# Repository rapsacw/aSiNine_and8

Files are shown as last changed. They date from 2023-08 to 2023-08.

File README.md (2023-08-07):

# aSiNine_and8
Small (46.5x73.2mm) BM1397 based standalone bitcoin miner

Revision 04k, remarks:
- PWM fan: do not populate T2,JP1 & R10, unless you want to use that feature (no software support yet), replace T2 with a mosfet if you want to use it, a transistor will pull gpio9 low at startup locking the esp in programming mode.
- programming first time: some esp's will not enter programming mode automatically, in that case short gpio9 to ground at power-up (gpio9 is connected to the encircled via close to the esp32-c3). Updating the firmware is best done through OTA @ <your miner's ip address>/update). You can also flash the esp with the ElegantOTA demo and then flash it first time over the air.
- Powering the miner: use a 5V/3A usb charger for low power application (upto ~250GHs). If you want more powerrr use the screw terminal to connect a 9-12V power supply. I use a usb trigger (like https://www.aliexpress.com/item/1005004562492420.html) set to 9V connected to a usb charger with PD (use a high efficiency charger like https://www.aliexpress.com/item/1005004530223949.html). IMPORTANT: only connect the miner with ONE of the power inputs. Powering the miner with more than 5V and connecting it to a PC will damage the miner and the pc!!!!
- Cooling: I use a 7cm piece of https://www.aliexpress.com/item/1005001772072504.html with a 5cm 5V fan (runs on 3.3V when connected to X1) like https://www.aliexpress.com/item/1005003059434065.html strapped to the heatsink and board with tie wraps. Don't forget to use some (non-conductive!) thermal compound. This fan/heatsink combo will allow the miner to be run at upto 320GHs while staying (just) below my max asic temperature of 60C and is virtually silent.
- The firmware used is bm1397.ino.bin included in this repo, and can be used until I update & publish the source code of my firmware.

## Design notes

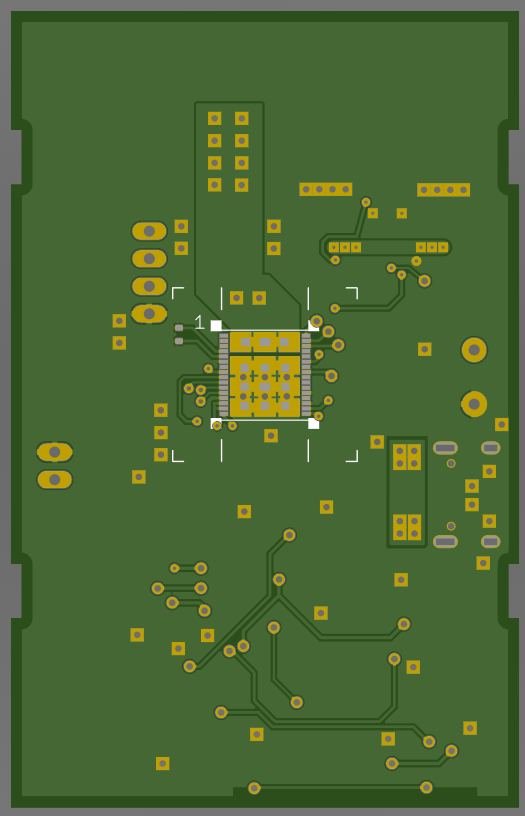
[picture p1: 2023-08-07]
and8bottom.png

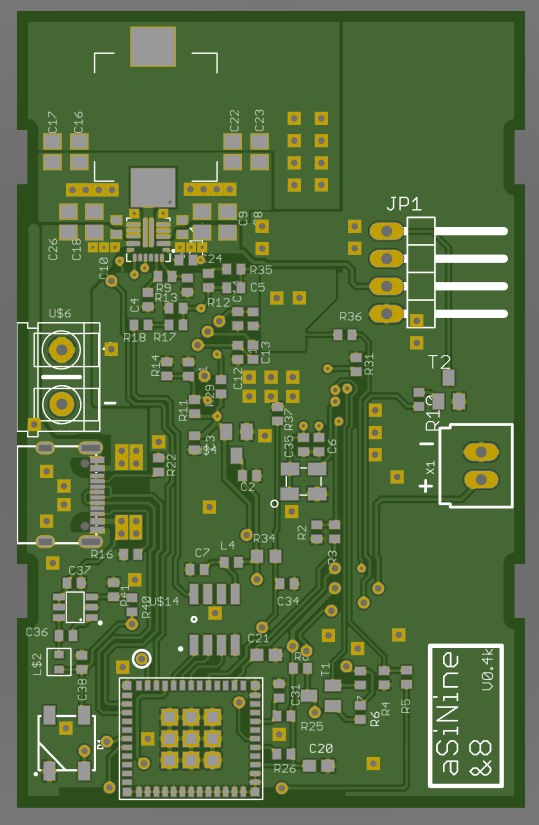
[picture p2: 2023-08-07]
and8top.png

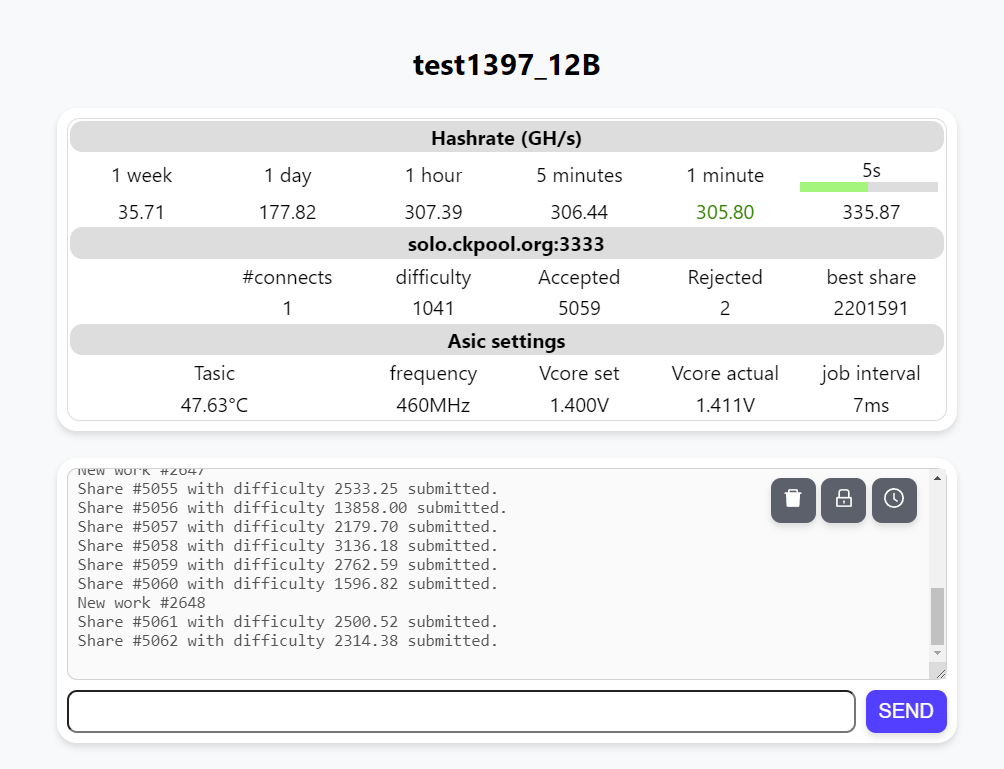
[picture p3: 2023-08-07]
ui.png

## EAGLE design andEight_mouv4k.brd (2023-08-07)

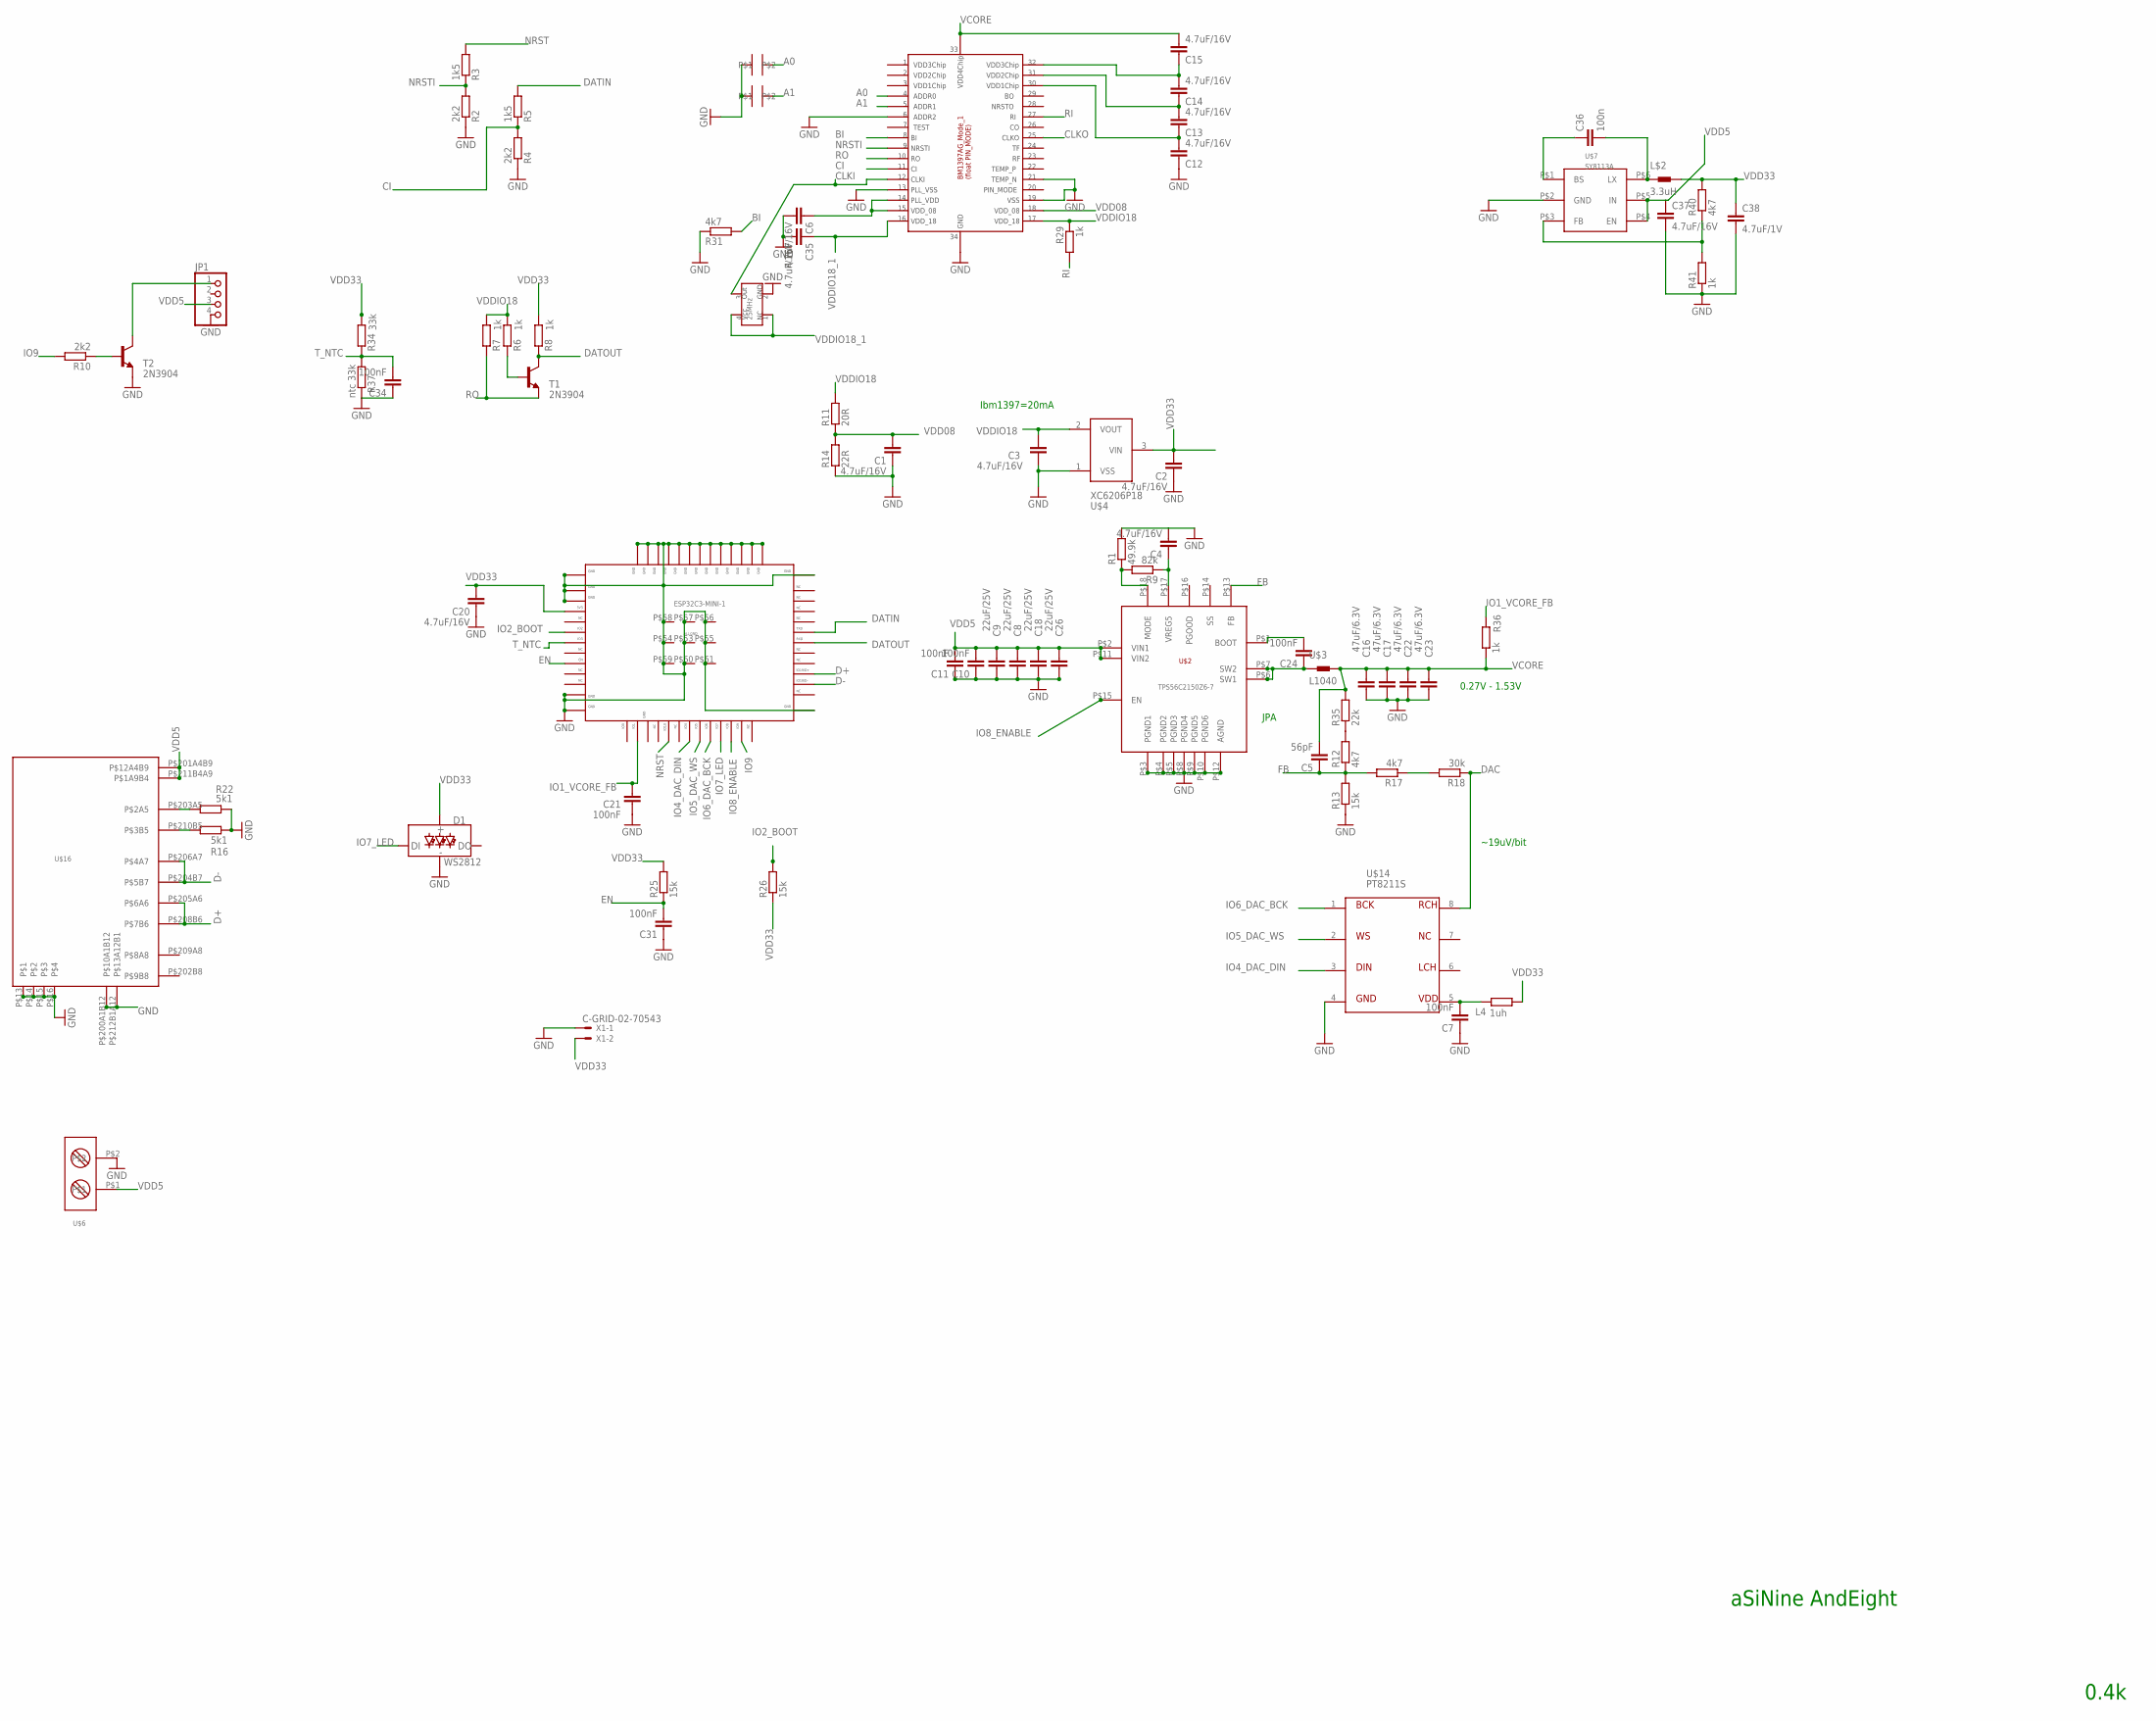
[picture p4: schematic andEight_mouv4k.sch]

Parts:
A0, A1: SOLDERJUMPER
C1, C2, C3, C4, C6, C12, C13, C14, C15, C35, C37: 4.7uF/16V; C0402
C5: 56pF; C0402
C7, C10, C11, C24, C31, C34: 100nF; C0402
C8, C9, C18, C26: 22uF/25V; C0805
C16, C17, C22, C23: 47uF/6.3V; C0805
C20: 4.7uF/16V; C0603
C21: 100nF; C0603
C36: 100n; C0402
C38: 4.7uF/1V; C0402
D1: WS2812; WS2812-5X5-4PIN
ESP32C3-MINI-1: ESP32-C3-MINI-1; ESP32C3MINI
JP1: PINHD-1X4/90; 1X04/90
L4: 1uh; R0402
L$2: 3.3uH; NR201610
R1: 49.9k; R0402
R2, R4, R10: 2k2; R0402
R3, R5: 1k5; R0402
R6, R7, R8, R29, R36, R41: 1k; R0402
R9: 82k; R0402
R11: 20R; R0402
R12, R17, R31, R40: 4k7; R0402
R13, R25, R26: 15k; R0402
R14: 22R; R0402
R16, R22: 5k1; R0402
R18: 30k; R0402
R34: 33k; R0603
R35: 22k; R0402
R37: ntc 33k; R0402
T1, T2: 2N3904; SOT23
U$1: BM1397-1; BM1391
U$2: TPS56C2150Z6-7; VQFN-HR
U$3: L1040
U$4: XC6206P18; SOT23
U$6: DG301-50
U$7: SY8113A; SOT23L-6
U$14: PT8211S; SO-8
U$16: USBCTHT; USBCSMTTHT
U$22: 25MHz; 3225
X1: C-GRID-02-70543; 70543-02

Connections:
A0: A0.P$1, U$1.P$4
A1: A1.P$1, U$1.P$5
BI: R31.2, U$1.P$8
CI: R4.2, R5.1, U$1.P$11
CLKI: U$1.P$12, U$22.P$3
CLKO: U$1.P$25
D+: ESP32C3-MINI-1.P$27, U$16.P$205A6 (P$6A6), U$16.P$208B6 (P$7B6)
D-: ESP32C3-MINI-1.P$26, U$16.P$204B7 (P$5B7), U$16.P$206A7 (P$4A7)
DAC: R18.1, U$14.8
DATIN: ESP32C3-MINI-1.P$31, R5.2
DATOUT: ESP32C3-MINI-1.P$30, R8.1, T1.3 (C)
EN: C31.2, ESP32C3-MINI-1.P$8, R25.1
FB: C5.1, R12.1, R13.2, R17.2, U$2.P$13 (FB)
GND: A0.P$2, A1.P$2, C1.1, C2.1, C3.1, C4.2, C6.2, C7.1, C8.2, C9.2, C10.1, C11.1, C12.1, C16.2, C17.2, C18.2, C20.1, C21.1, C22.2, C23.2, C26.2, C31.1, C34.1, C35.2, C37.2, C38.2, D1.GND, ESP32C3-MINI-1.P$1, ESP32C3-MINI-1.P$2, ESP32C3-MINI-1.P$11, ESP32C3-MINI-1.P$36, ESP32C3-MINI-1.P$37, ESP32C3-MINI-1.P$38, ESP32C3-MINI-1.P$39, ESP32C3-MINI-1.P$40, ESP32C3-MINI-1.P$41, ESP32C3-MINI-1.P$42, ESP32C3-MINI-1.P$43, ESP32C3-MINI-1.P$44, ESP32C3-MINI-1.P$45, ESP32C3-MINI-1.P$46, ESP32C3-MINI-1.P$47, ESP32C3-MINI-1.P$48, ESP32C3-MINI-1.P$49, ESP32C3-MINI-1.P$50, ESP32C3-MINI-1.P$51, ESP32C3-MINI-1.P$52, ESP32C3-MINI-1.P$53, ESP32C3-MINI-1.P$54, ESP32C3-MINI-1.P$55, ESP32C3-MINI-1.P$56, ESP32C3-MINI-1.P$57, ESP32C3-MINI-1.P$58, ESP32C3-MINI-1.P$59, ESP32C3-MINI-1.P$60, ESP32C3-MINI-1.P$61, JP1.4, R1.2, R2.1, R4.1, R13.1, R14.2, R16.2, R22.2, R31.1, R37.1, R41.1, T2.2 (E), U$1.P$6, U$1.P$13, U$1.P$19, U$1.P$21, U$1.P$34, U$2.P$3 (PGND1), U$2.P$4 (PGND2), U$2.P$5 (PGND3), U$2.P$8 (PGND4), U$2.P$9 (PGND5), U$2.P$10 (PGND6), U$2.P$12 (AGND), U$4.1 (VSS), U$6.P$2, U$7.P$2 (GND), U$14.4, U$16.P$13, U$16.P$14, U$16.P$15, U$16.P$16, U$16.P$200A1B12 (P$10A1B12), U$16.P$212B1A12 (P$13A12B1), U$22.P$2, X1.1
IO1_VCORE_FB: C21.2, ESP32C3-MINI-1.P$13, R36.2
IO2_BOOT: ESP32C3-MINI-1.P$5, R26.2
IO4_DAC_DIN: ESP32C3-MINI-1.P$18, U$14.3
IO5_DAC_WS: ESP32C3-MINI-1.P$19, U$14.2
IO6_DAC_BCK: ESP32C3-MINI-1.P$20, U$14.1
IO7_LED: D1.DI, ESP32C3-MINI-1.P$21
IO8_ENABLE: ESP32C3-MINI-1.P$22, U$2.P$15 (EN)
IO9: ESP32C3-MINI-1.P$23, R10.2
unnamed: R10.1, T2.1 (B)
unnamed: C24.2, U$2.P$1 (BOOT)
unnamed: C24.1, U$2.P$6 (SW1), U$2.P$7 (SW2), U$3.P$1 (1)
unnamed: C4.1, R9.1, U$2.P$17 (VREG5)
unnamed: R1.1, R9.2, U$2.P$18 (MODE)
unnamed: JP1.1, T2.3 (C)
unnamed: C36.1, U$7.P$1 (BS)
unnamed: C36.2, L$2.P$1 (1), U$7.P$6 (LX)
unnamed: R40.1, R41.2, U$7.P$3 (FB)
unnamed: R16.1, U$16.P$210B5 (P$3B5)
unnamed: R22.1, U$16.P$203A5 (P$2A5)
unnamed: R6.1, T1.1 (B)
unnamed: R12.2, R35.1
unnamed: R17.1, R18.2
NRST: ESP32C3-MINI-1.P$16, R3.2
NRSTI: R2.2, R3.1, U$1.P$9
P$5: C7.2, L4.2, U$14.5
RI: R29.2, U$1.P$27
RO: R7.1, T1.2 (E), U$1.P$10
T_NTC: C34.2, ESP32C3-MINI-1.P$6, R34.1, R37.2
VCORE: C5.2, C15.2, C16.1, C17.1, C22.1, C23.1, R35.2, R36.1, U$1.P$33, U$3.P$2 (2)
VDD1: C12.2, C13.1, U$1.P$30
VDD2: C13.2, C14.1, U$1.P$31
VDD3: C14.2, C15.1, U$1.P$32
VDD5: C8.1, C9.1, C10.2, C11.2, C18.1, C26.1, C37.1, JP1.3, U$2.P$2 (VIN1), U$2.P$11 (VIN2), U$6.P$1, U$7.P$4 (EN), U$7.P$5 (IN), U$16.P$201A4B9 (P$12A4B9), U$16.P$211B4A9 (P$1A9B4)
VDD08: C1.2, R11.2, R14.1, U$1.P$18
VDD08_1: C6.1, U$1.P$14, U$1.P$15
VDD33: C2.2, C20.2, C38.1, D1.VCC, ESP32C3-MINI-1.P$3, L4.1, L$2.P$2 (2), R8.2, R25.2, R26.1, R34.2, R40.2, U$4.3 (VIN), X1.2
VDDIO18: C3.2, R6.2, R7.2, R11.1, R29.1, U$1.P$17, U$4.2 (VOUT)
VDDIO18_1: C35.1, U$1.P$16, U$22.P$1, U$22.P$4

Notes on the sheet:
0.27V - 1.53V
JPA
aSiNine AndEight
0.4k
~19uV/bit
Ibm1397=20mA

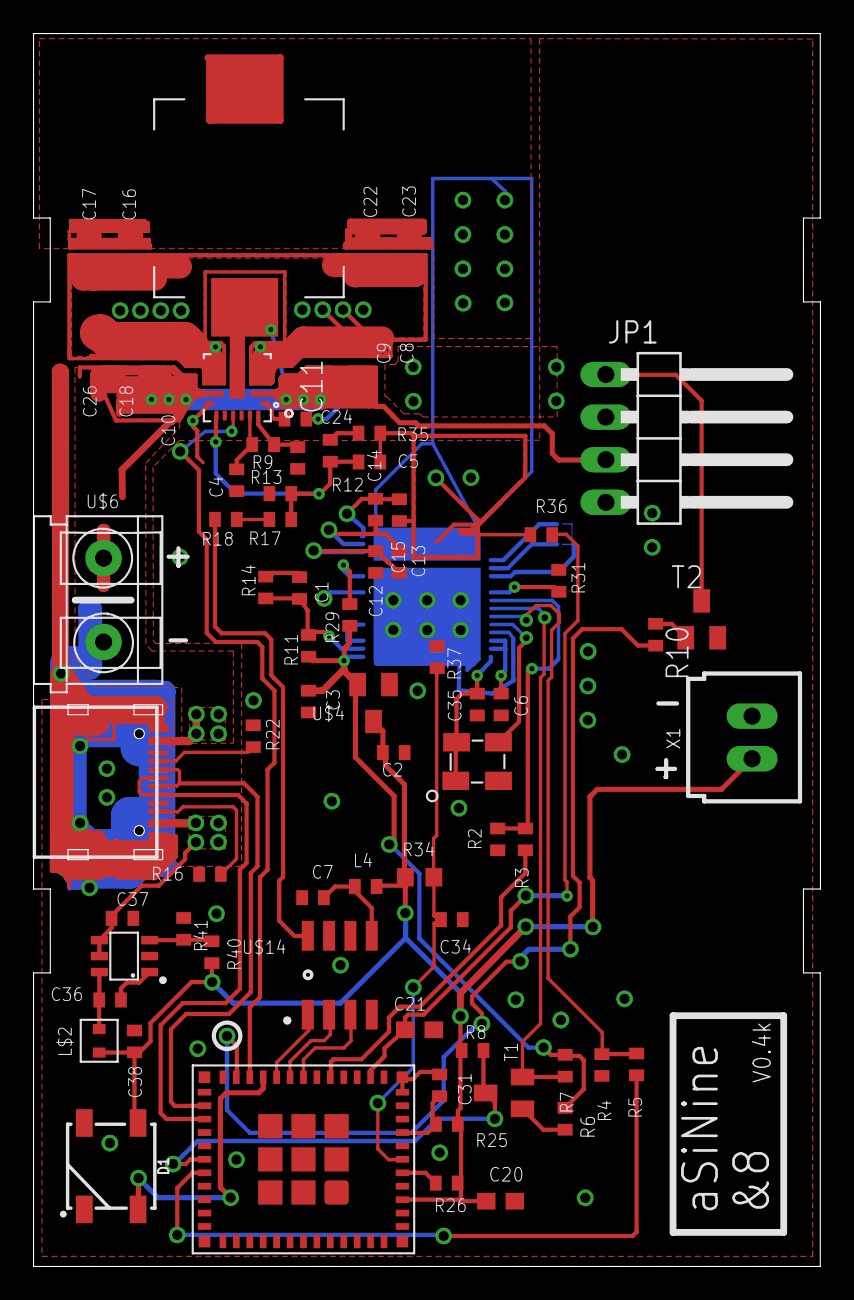
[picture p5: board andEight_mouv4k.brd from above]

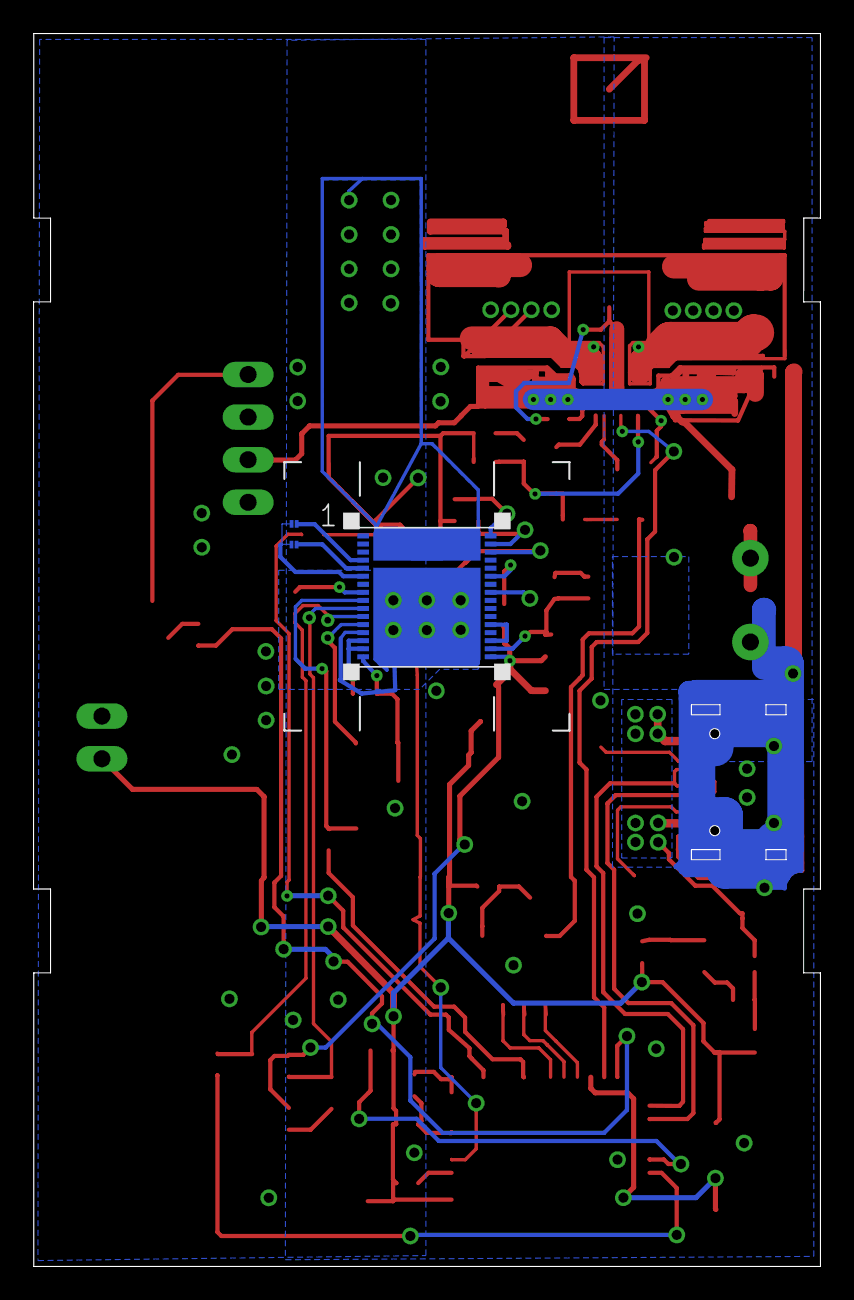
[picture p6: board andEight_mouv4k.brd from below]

Board: 2 copper layers, 46.9 x 73.5 mm, 77 parts (3 on the bottom side), 51 nets.

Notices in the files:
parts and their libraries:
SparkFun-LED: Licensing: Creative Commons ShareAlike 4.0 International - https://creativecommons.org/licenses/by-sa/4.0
